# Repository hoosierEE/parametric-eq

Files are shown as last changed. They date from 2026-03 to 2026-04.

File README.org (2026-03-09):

* Parseq (Parametric Equalizer)

/(Par)ametric + (s)helving (eq)ualizer ⇒ Parseq/

An equalizer (EQ) effect is an understated workhorse. It expands the capabilities of your existing pedals, can fix sonic problems with surgical precision, or simply add a different color to your palette.

Graphic EQs can't be beat for their easy-to-use interface, but all those sliders take up a lot of space and cutting long slots in an enclosure isn't as DIY-friendly as a design with rotary knobs.

Fully parametric EQs are still EQs but in practice they fill a different niche than a graphic EQ. Rather than constructing a frequency response graph, a fully parametric EQ excels at pinpointing a specific frequency to cut or boost with precision.

[[https://www.falstad.com/afilter/circuitjs.html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][This design]] takes a lot of inspiration from [[https://bentfishbowl.wixsite.com/electronics/post/core-shaper][Dylan's Core Shaper]], another EQ with a parametric midrange. The Core Shaper is a simpler design (only 4 op-amps required) with a semi-parametric midrange control based on a Wein bridge filter. The mid sweep of the Core Shaper extends from about 310Hz to 3.2kHz. The Q in the Core Shaper is switchable from low (~0.3) to high (~0.8)

#+caption: Parseq schematic
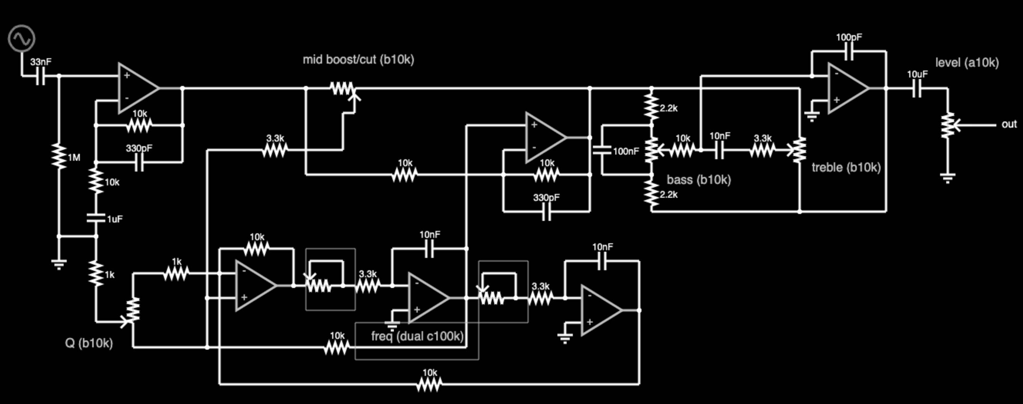
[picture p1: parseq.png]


NOTE: table contains *simulated* values

| mid parameter  | Core Shaper | Parseq |
|----------------+-------------+--------|
| min freq (Hz)  |         311 |    155 |
| max freq (Hz)  |        3220 |   4180 |
| min Q          |         0.3 |    0.3 |
| max Q          |         0.8 |    2.4 |
| max boost (dB) |          16 |     15 |
| max cut (dB)   |         -16 |    -16 |

By contrast, the Parseq uses a state variable filter for the midrange which gives it a wider bandwidth sweep as well as continuous control over the Q factor instead of a 2-mode switch. The downside of this design is it requires more components.

Besides the mid filter, the Parseq takes nearly all of its design cues from the Core Shaper:

1. input fixed gain stage
2. parametric midrange
3. Baxandall treble/bass shelving filters
4. passive output attenuator for volume control

Use the Parseq when you want more precision than the Core Shaper and don't mind the extra circuit complexity.

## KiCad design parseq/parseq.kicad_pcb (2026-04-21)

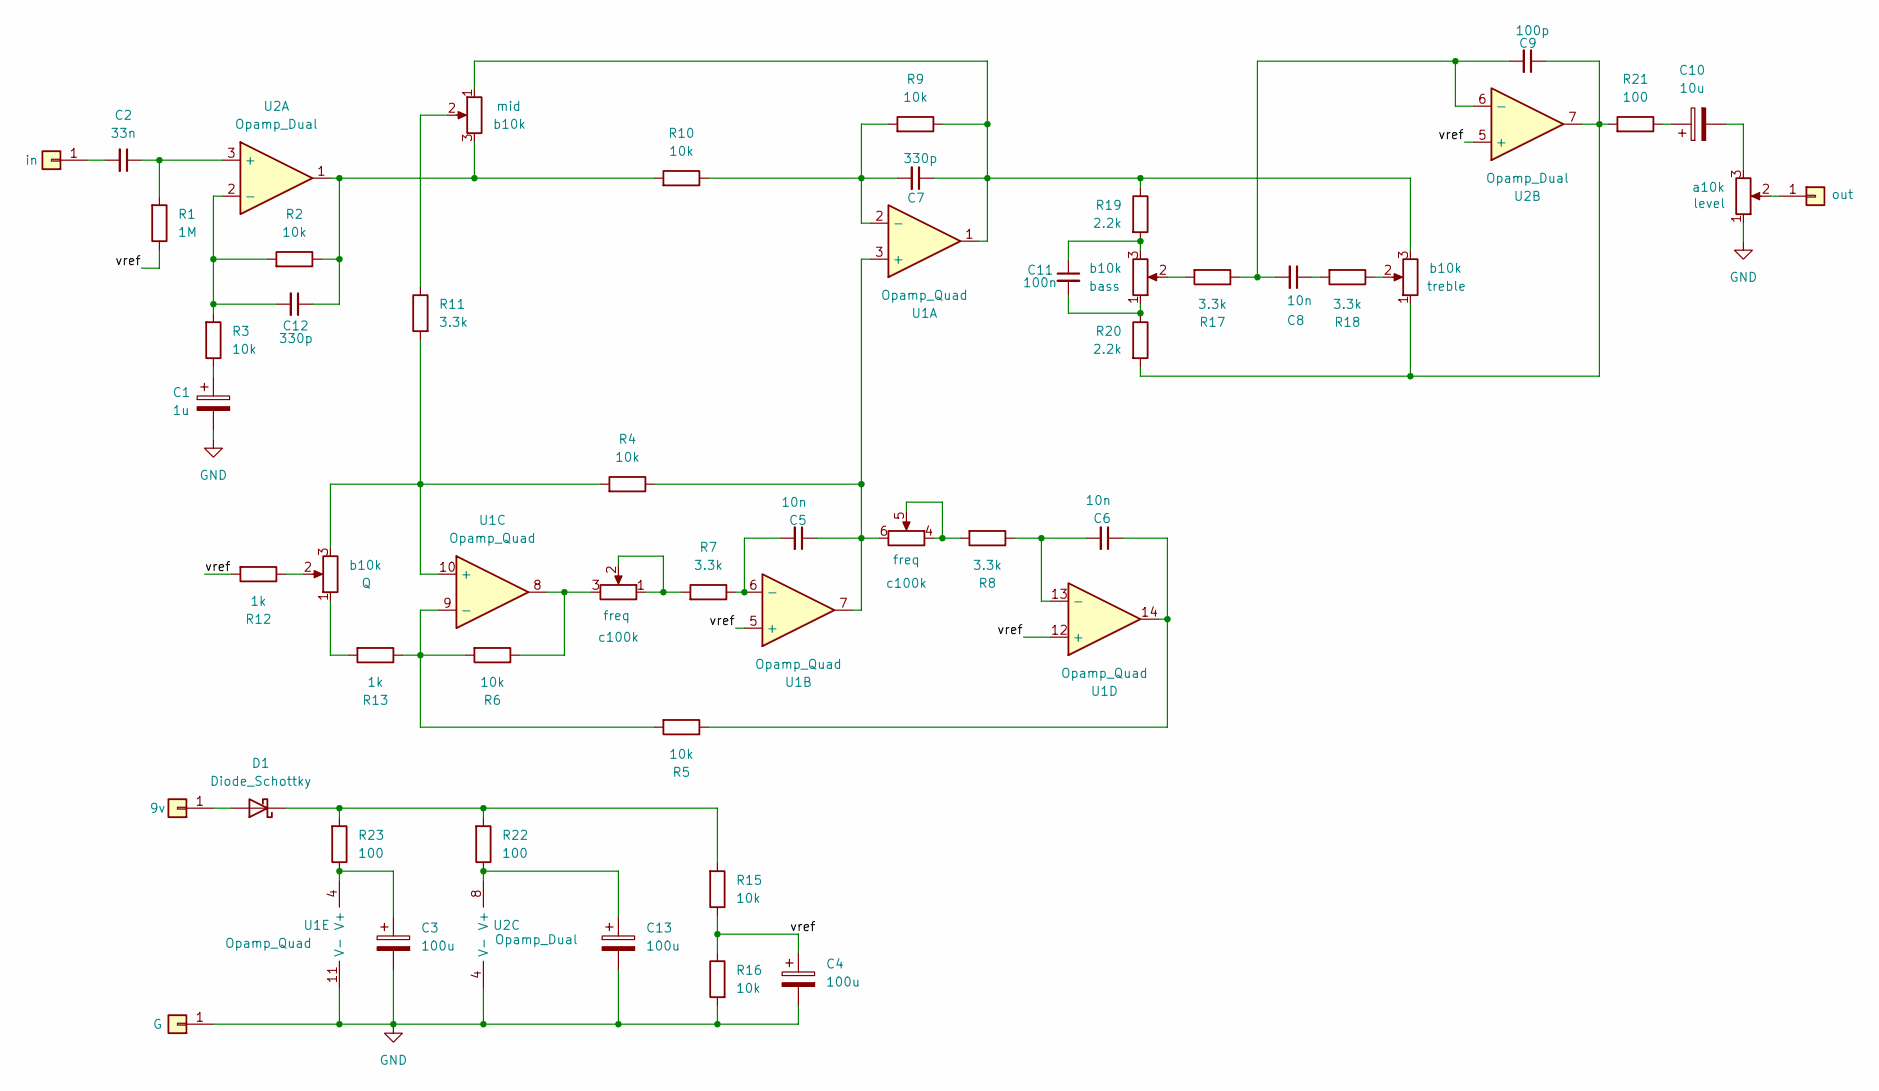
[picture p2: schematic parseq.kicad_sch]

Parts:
C1: 1u; CP_ELCO_1x2_S
C2: 33n; C_CERAMIC_1x2
C3, C4, C13: 100u; CP_ELCO_1x2_S
C5, C6, C8: 10n; C_CERAMIC_1x2
C7, C12: 330p; C_CERAMIC_1x2
C9: 100p; C_CERAMIC_1x2
C10: 10u; CP_ELCO_1x2_S
C11: 100n; C_CERAMIC_1x2
D1: Diode_Schottky; D_A-405_P7.62mm_Horizontal
J1, J2, J3, J4: Conn_01x01; PAD_1_std_sqr
R1: 1M; R_1x4
R2, R3, R4, R5, R6, R9, R10, R15, R16: 10k; R_1x4
R7, R8, R11, R17, R18: 3.3k; R_1x4
R12, R13: 1k; R_1x4
R19, R20: 2.2k; R_1x4
R21, R22, R23: 100; R_1x4
RV1: c100k; Potentiometer_Alpha_RD902F-40-00D_Dual_Vertical
RV2, RV3, RV4, RV5: b10k; Potentiometer_Alpha_RD901F-40-00D_Single_Vertical
RV6: a10k; Potentiometer_Alpha_RD901F-40-00D_Single_Vertical
U1: Opamp_Quad; DIP-14
U2: Opamp_Dual; DIP-8

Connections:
/vref: C4.1, R1.2, R12.1, R15.2, R16.2, U1.5 (+), U1.12 (+), U2.5 (+)
GND: C1.2, C3.2, C4.2, C13.2, J2.1, R16.1, RV6.1, U1.11 (V-), U2.4 (V-)
unnamed: C1.1, R3.2
unnamed: C6.1, R5.2, U1.14
unnamed: C7.1, R9.2, R19.2, RV2.1, RV5.3, U1.1
unnamed: C8.1, R18.1
unnamed: C9.1, R20.1, R21.1, RV5.1, U2.7
unnamed: C10.1, R21.2
unnamed: C10.2, RV6.3
unnamed: C11.1, R19.1, RV4.3
unnamed: C11.2, R20.2, RV4.1
unnamed: C12.1, R2.2, R10.1, RV2.3, U2.1
unnamed: D1.2 (A), J1.1
unnamed: D1.1 (K), R15.1, R22.1, R23.1
unnamed: C2.2, J3.1
unnamed: J4.1, RV6.2
unnamed: R8.1, RV1.4, RV1.5
unnamed: R11.2, RV2.2
unnamed: R12.2, RV3.2
unnamed: R13.1, RV3.1
unnamed: R17.1, RV4.2
unnamed: R18.2, RV5.2
unnamed: R7.1, RV1.1 (4), RV1.2 (5)
unnamed: R6.2, RV1.3 (6), U1.8
unnamed: C5.1, R4.2, RV1.6, U1.3 (+), U1.7
unnamed: C7.2, R9.1, R10.2, U1.2 (-)
unnamed: C5.2, R7.2, U1.6 (-)
unnamed: R4.1, R11.1, RV3.3, U1.10 (+)
unnamed: R5.1, R6.1, R13.2, U1.9 (-)
unnamed: C6.2, R8.2, U1.13 (-)
unnamed: C3.1, R23.2, U1.4 (V+)
unnamed: C2.1, R1.1, U2.3 (+)
unnamed: C12.2, R2.1, R3.1, U2.2 (-)
unnamed: C8.2, C9.2, R17.2, U2.6 (-)
unnamed: C13.1, R22.2, U2.8 (V+)

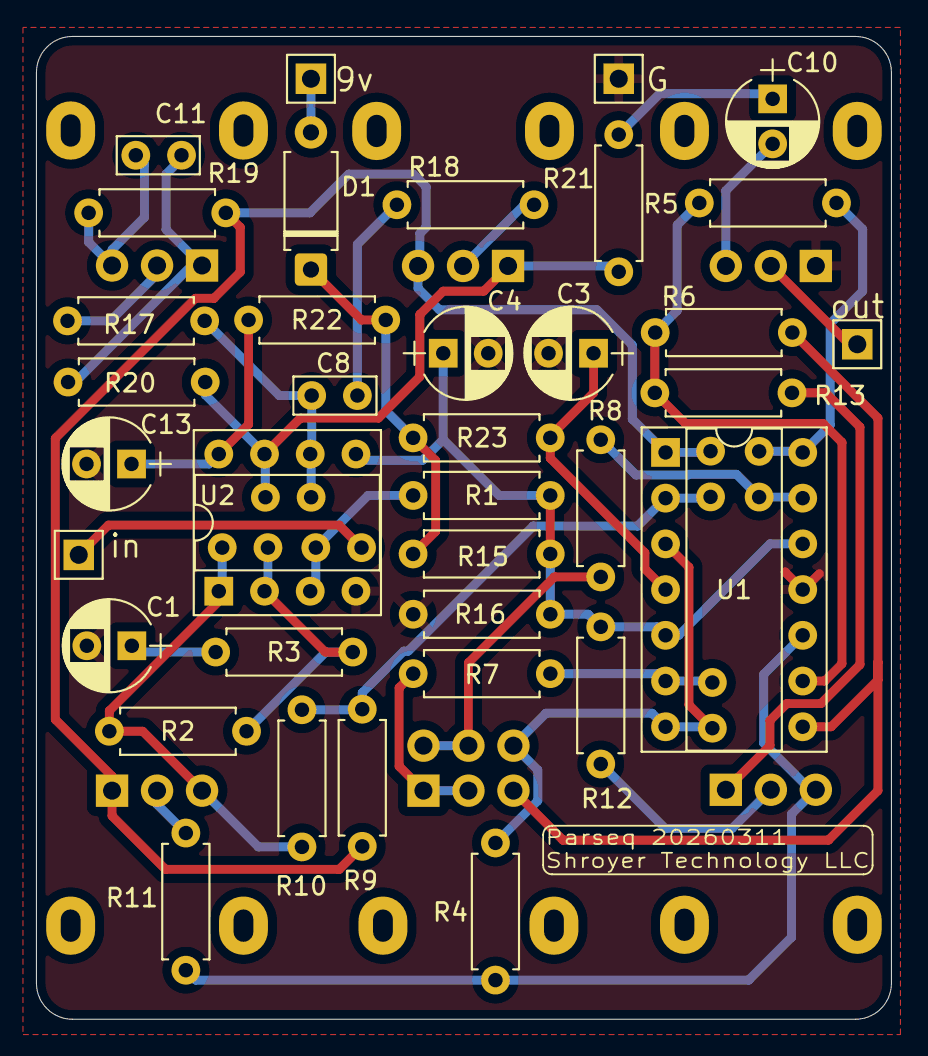
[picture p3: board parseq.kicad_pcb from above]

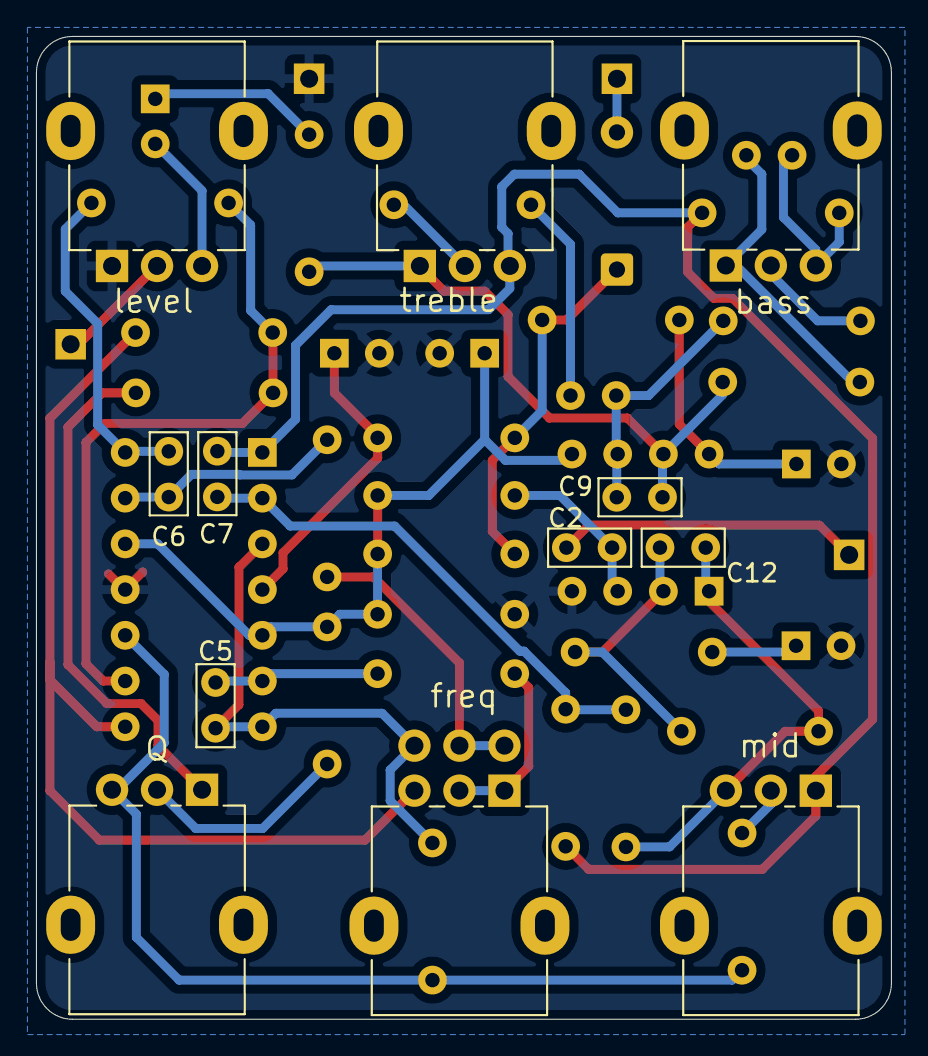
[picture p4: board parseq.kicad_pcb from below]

Board: 2 copper layers, 47.5 x 54.6 mm, 48 parts (12 on the bottom side), 35 nets.

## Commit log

2026-03-09 all nets routed
    [parseq.kicad_pcb, parseq.kicad_sch]
2026-03-11 update board
    [parseq.kicad_pcb, parseq.kicad_sch]
2026-03-11 shorter tracks
    [parseq.kicad_pcb]
2026-03-12 add name and version to silkscreen
    [parseq.kicad_pcb, parseq.kicad_sch]
